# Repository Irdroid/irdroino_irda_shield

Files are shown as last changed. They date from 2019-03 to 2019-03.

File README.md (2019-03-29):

# Irdroino irDA Shield

The Irdroino IrDA shield is a shield for Arduino that will allow you to communicate with IrDA compiant equipment such as devices that support IrDA SIR communication up to 115200 bps (Power Meters, PDAs , data acquisition devices and other devices that communicate via IrDA SIR ).

- Compatible with Arduino UNO board layouts
- Supports with IrDA® Physical Layer Specification (version 1.3)
- High quality infrared transceiver
- Up to *5 meters IrDA SIR communication
- Supports baud rates from 9600 – 115200 bps
- Demo code that demostrates how to communicate with the Shield

### Version
1.0
### Grab a sample

You can grab a sample board from https://irdroid.eu/product/irdroino-irda-shield/

### Todos

 - n/a
 
License
----
GPL 2.0

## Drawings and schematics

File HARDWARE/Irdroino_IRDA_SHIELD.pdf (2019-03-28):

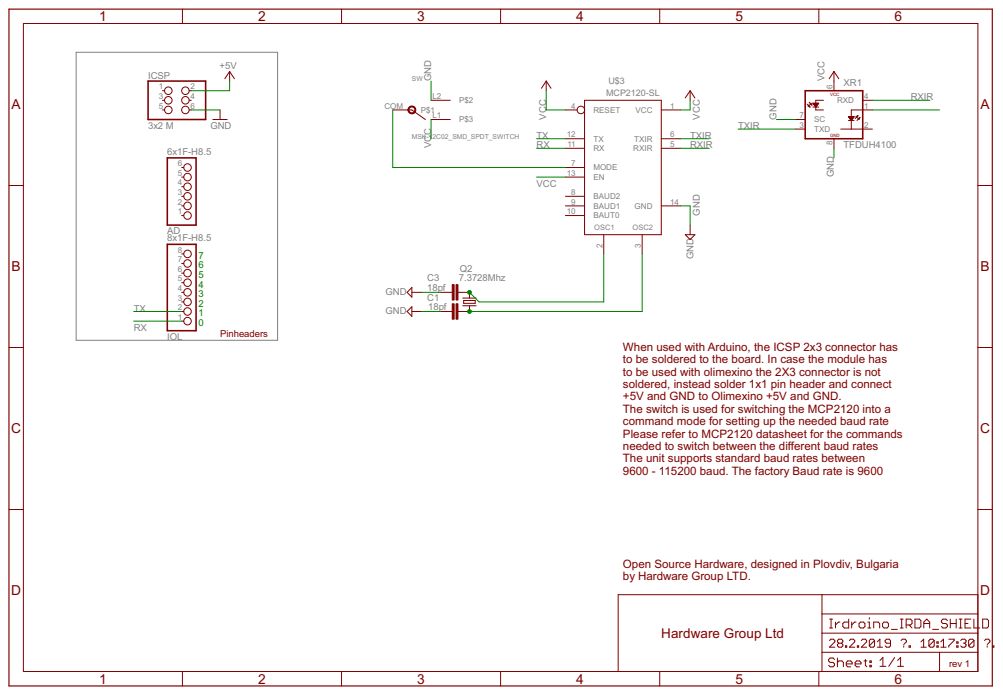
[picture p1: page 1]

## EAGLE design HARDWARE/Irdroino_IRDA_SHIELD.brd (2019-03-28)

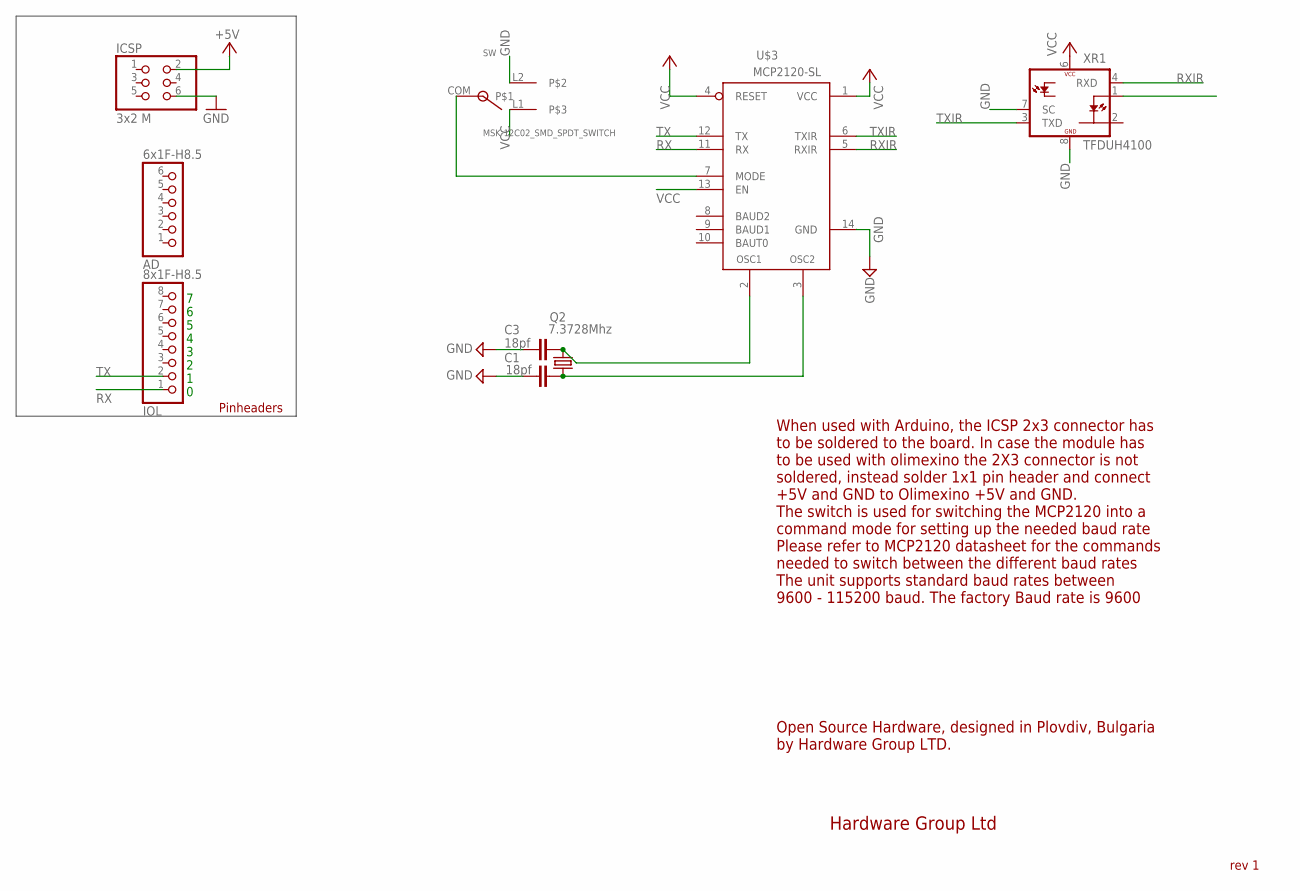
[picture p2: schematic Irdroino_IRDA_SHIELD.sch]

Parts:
AD: 6x1F-H8.5; 1X06
C1, C3: 18pf; C603
ICSP: 3x2 M; 2X03
IOL: 8x1F-H8.5; 1X08
Q2: 7.3728Mhz; HC49UP
SW: MSK-12C02_SMD_SPDT_SWITCH; MSK-12C02
U$3: MCP2120-SL; SO-14
XR1: TFDUH4100; TFDU4-HOR

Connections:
GND: C1.2, C3.2, ICSP.6, SW.L2, U$3.14 (GND), XR1.7 (SC), XR1.8 (GND)
unnamed: C3.1, Q2.2, U$3.2 (OSC1)
unnamed: C1.1, Q2.1, U$3.3 (OSC2)
unnamed: SW.COM, U$3.7 (MODE)
RX: IOL.1, U$3.11 (RX)
RXIR: U$3.5 (RXIR), XR1.4 (RXD)
TX: IOL.2, U$3.12 (TX)
TXIR: U$3.6 (TXIR), XR1.3 (TXD)
VCC: ICSP.2, SW.L1, U$3.1 (VCC), U$3.4 (RESET), U$3.13 (EN), XR1.1 (IRED-A), XR1.6 (VCC)

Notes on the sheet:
Pinheaders
Hardware Group Ltd
rev 1
When used with Arduino, the ICSP 2x3 connector has to be soldered to the board. In case the module has to be used with olimexino the 2X3 connector is not soldered, instead solder 1x1 pin header and connect +5V and GND to Olimexino +5V and GND. The switch is used for switching the MCP2120 into a com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
Open Source Hardware, designed in Plovdiv, Bulgaria by Hardware Group LTD.

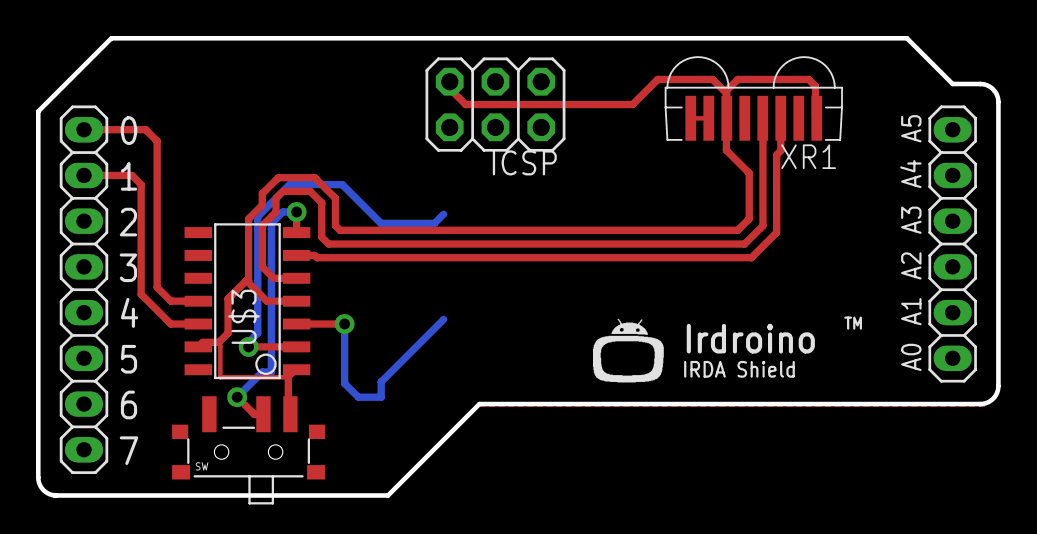
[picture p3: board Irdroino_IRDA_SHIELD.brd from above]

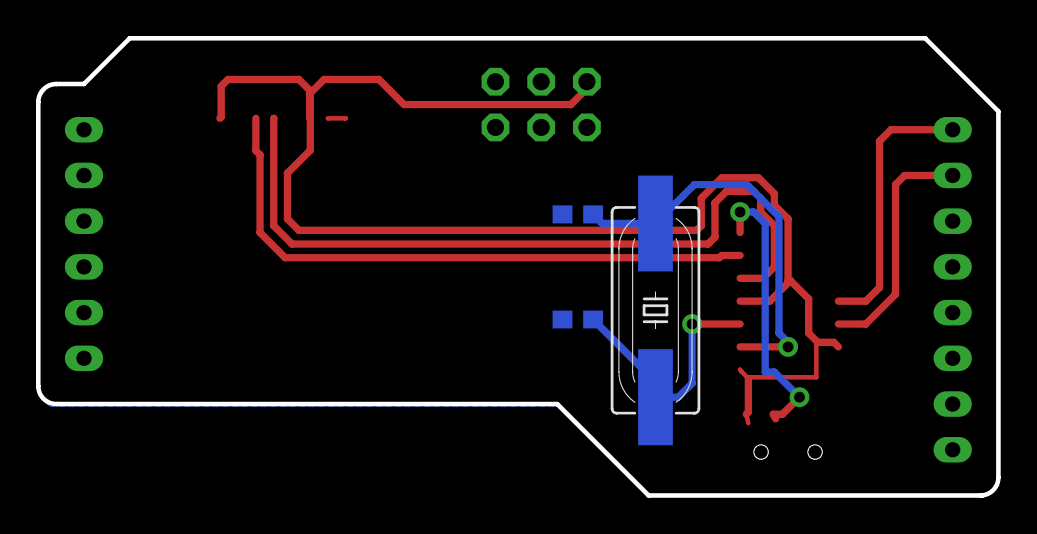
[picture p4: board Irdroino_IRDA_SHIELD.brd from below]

Board: 2 copper layers, 53.3 x 25.4 mm, 10 parts (3 on the bottom side), 9 nets.

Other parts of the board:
U$2: IRDROIDLOGO

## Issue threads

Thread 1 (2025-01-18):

Sketch upload fails when hat is attached

gearmo3ds, 2025-01-18:
Hello,

when the hat is attached I am unable to upload the example sketch to the UNO via arduino-ide:

```
Sketch uses 1614 bytes (5%) of program storage space. Maximum is 32256 bytes.
Global variables use 196 bytes (9%) of dynamic memory, leaving 1852 bytes for local variables. Maximum is 2048 bytes.
avrdude: stk500_getsync() attempt 1 of 10: not in sync: resp=0x00
avrdude: stk500_getsync() attempt 2 of 10: not in sync: resp=0x00
avrdude: stk500_getsync() attempt 3 of 10: not in sync: resp=0x00
avrdude: stk500_getsync() attempt 4 of 10: not in sync: resp=0x00
avrdude: stk500_getsync() attempt 5 of 10: not in sync: resp=0x00
avrdude: stk500_getsync() attempt 6 of 10: not in sync: resp=0x00
avrdude: stk500_getsync() attempt 7 of 10: not in sync: resp=0x00
avrdude: stk500_getsync() attempt 8 of 10: not in sync: resp=0x00
avrdude: stk500_getsync() attempt 9 of 10: not in sync: resp=0x00
avrdude: stk500_getsync() attempt 10 of 10: not in sync: resp=0x00
Failed uploading: uploading error: exit status 1
```

As soon as I remove the hat, uploading works again.

What may I be doing wrong?

Irdroid, 2025-01-19:
I think this is a limitation of the hardware , because the serial port which is wired to communicate with the mcp2120 is also used for programming. This means the shield must be removed when programming

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
--
-- Irdroid ---------------
Mobile: +359 890325649
email: ***@***.***

We recommend encrypted communication, using PGP, please find our Public PGP key below and consider using end-to-end message encryption with your email client.

OpenPGP Public key:
---------------------------------

https://keys.openpgp.org/vks/v1/by-fingerprint/3198C0EB6203A92259F3748B43F0EB16221CF3F0

gearmo3ds, 2025-01-19:
Thanks for the quick reply, this works indeed.

How can I set the baudrate via software?
https://irdroid.eu/product/irdroino-irda-shield/
I cannot find the command-mode switch on the board that is mentioned in the description, does it require soldering?
How can I activate the command mode to then send the hex commands similar to described here?
https://irdroid.eu/set-irdroid-usb-irda-sir-baud-rate/

I would like to set the board's rate to 115200 permanently.

Irdroid, 2025-01-19:
The baud rate is configured with three solder jumpers. By default they are in 0,0,0 configuration which is 9600 baud . To see the other modes check the mcp2120 datasheet

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
--
-- Irdroid ---------------
Mobile: +359 890325649
email: ***@***.***

We recommend encrypted communication, using PGP, please find our Public PGP key below and consider using end-to-end message encryption with your email client.

OpenPGP Public key:
---------------------------------

https://keys.openpgp.org/vks/v1/by-fingerprint/3198C0EB6203A92259F3748B43F0EB16221CF3F0
